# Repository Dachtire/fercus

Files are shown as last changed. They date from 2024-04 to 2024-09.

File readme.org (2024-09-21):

#+TITLE: Fercus
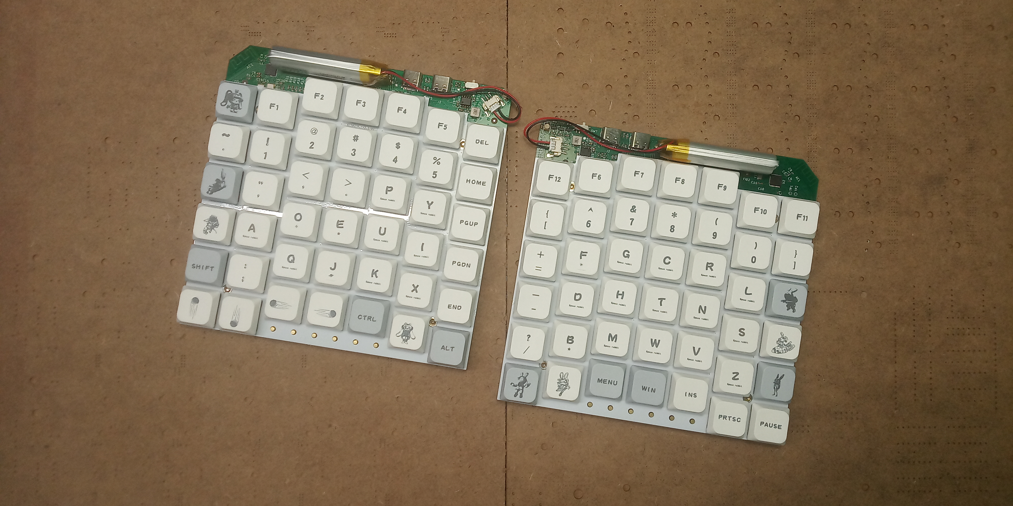
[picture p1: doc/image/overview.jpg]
Wireless Symmetry Optical Keyboard

* Firmware
** Connect via RF 2.4GHz Proprietary, BLE 5.3, USB
** COMMENT optical switch with diff trigger mode
# - schmitt trigger
# - adc trigger
# - adc difference
** COMMENT function
# - multiple layers
# - repeat mode

* Hardware
** Switch
6*7 keys of each side, low profile optical switch
# - raesha low profile optical switch
# - keychron low profile optical switch
# - razer low profile optical switch

** Spec
Dimension: 133 * 137 * 14.35 mm

Weight of each side: 159 ± 1 g

power input: DC 5V 500mA

# current: 40 mA * 7 * 15 / 1000 = 4.2 mA

** response time
|    |       tr |       tf | unit |
| pt |       18 |        5 | us   |
# | sw | 200-2000 | 200-2000 | us   |
The speed of optical switch depends on the speed of finger, the shortest time for finger to press a switch is about 200 us, but usually it takes a few milliseconds.
Test on mcu's adc at f_adc = 12MHz, f_s = 12 / 14 MHz, resolution = 12 bits. Get the average of the five.

** COMMENT test
|    | min | typ | max | unit | cond                    |
| pt | 0.2 |     | 0.3 | V    | ir 20mA, without switch |

* Manual
** fn key
fn1: switch layout

fn2: switch connection mode. long press: rf Unbind with dongle

fn3: battery status

fn4: power on led green. power off led red.

** usb connection
- usb1 to connect with pc
#+begin_src org
              ┌────┐              
              │ pc │              
              └▲──▲┘              
               │  │               
    ┌───usb────┘  └────usb───┐    
    │                        │    
┌───▼──┬──────┐    ┌──────┬──▼───┐
│ usb1 │ usb2 │    │ usb2 │ usb1 │
├──────┴──────┤    ├──────┴──────┤
│    left     │    │    right    │
└─────────────┘    └─────────────┘
#+end_src
- usb2 to connect between left and right
#+begin_src org
              ┌────┐                                 ┌────┐              
              │ pc │                                 │ pc │              
              └▲───┘                                 └───▲┘              
               │                                         │               
    ┌───usb────┘                                         └────usb───┐    
    │                                                               │    
    │      ┌───usb────┐                           ┌───usb────┐      │    
    │      │          │                           │          │      │    
┌───▼──┬───▼──┐    ┌──▼───┬──────┐     ┌──────┬───▼──┐    ┌──▼───┬──▼───┐
│ usb1 │ usb2 │    │ usb2 │ usb1 │     │ usb1 │ usb2 │    │ usb2 │ usb1 │
├──────┴──────┤    ├──────┴──────┤     ├──────┴──────┤    ├──────┴──────┤
│    left     │    │    right    │     │    left     │    │    right    │
└─────────────┘    └─────────────┘     └─────────────┘    └─────────────┘
#+end_src

#               ┌────┐              
#               │ pc │              
#               └▲──▲┘              
#                │  │               
#     ┌───usb────┘  └────usb───┐    
#     │                        │    
#     │      ┌───usb────┐      │    
#     │      │          │      │    
# ┌───▼──┬───▼──┐    ┌──▼───┬──▼───┐
# │ usb1 │ usb2 │    │ usb2 │ usb1 │
# ├──────┴──────┤    ├──────┴──────┤
# │    left     │    │    right    │
# └─────────────┘    └─────────────┘

** RF connection
#+begin_src org
              ┌────┐              
              │ pc │              
              └─▲──┘              
                │usb              
             ┌──▼───┐             
  ┌─wireless─►dongle◄─wireless─┐  
  │          └──────┘          │  
  │                            │  
┌─▼───────────┐    ┌───────────▼─┐
│     RF      │    │     RF      │
├─────────────┤    ├─────────────┤
│    left     │    │    right    │
└─────────────┘    └─────────────┘
#+end_src

** BLE connection
#+begin_src org
              ┌────┐              
  ┌─wireless──► pc ◄──wireless─┐  
  │           └────┘           │  
  │                            │  
┌─▼───────────┐    ┌───────────▼─┐
│    BLE      │    │    BLE      │
├─────────────┤    ├─────────────┤
│    left     │    │    right    │
└─────────────┘    └─────────────┘
#+end_src

** mix connection
#+begin_src org
              ┌────┐              
              │ pc │              
              └▲───┘              
               │                  
    ┌───usb────┘                  
    │                             
    │      ┌─wireless─┐           
    │      │          │           
┌───▼──┬───▼──┐    ┌──▼───┬──────┐
│ usb1 │  RF  │    │  RF  │ usb1 │
├──────┴──────┤    ├──────┴──────┤
│    left     │    │    right    │
└─────────────┘    └─────────────┘
#+end_src

** power
auto power on/off when usb cable connected/disconnected

when idle for a week, first use fn4 to power off in firmware, then turn off hardware power switch

** layout
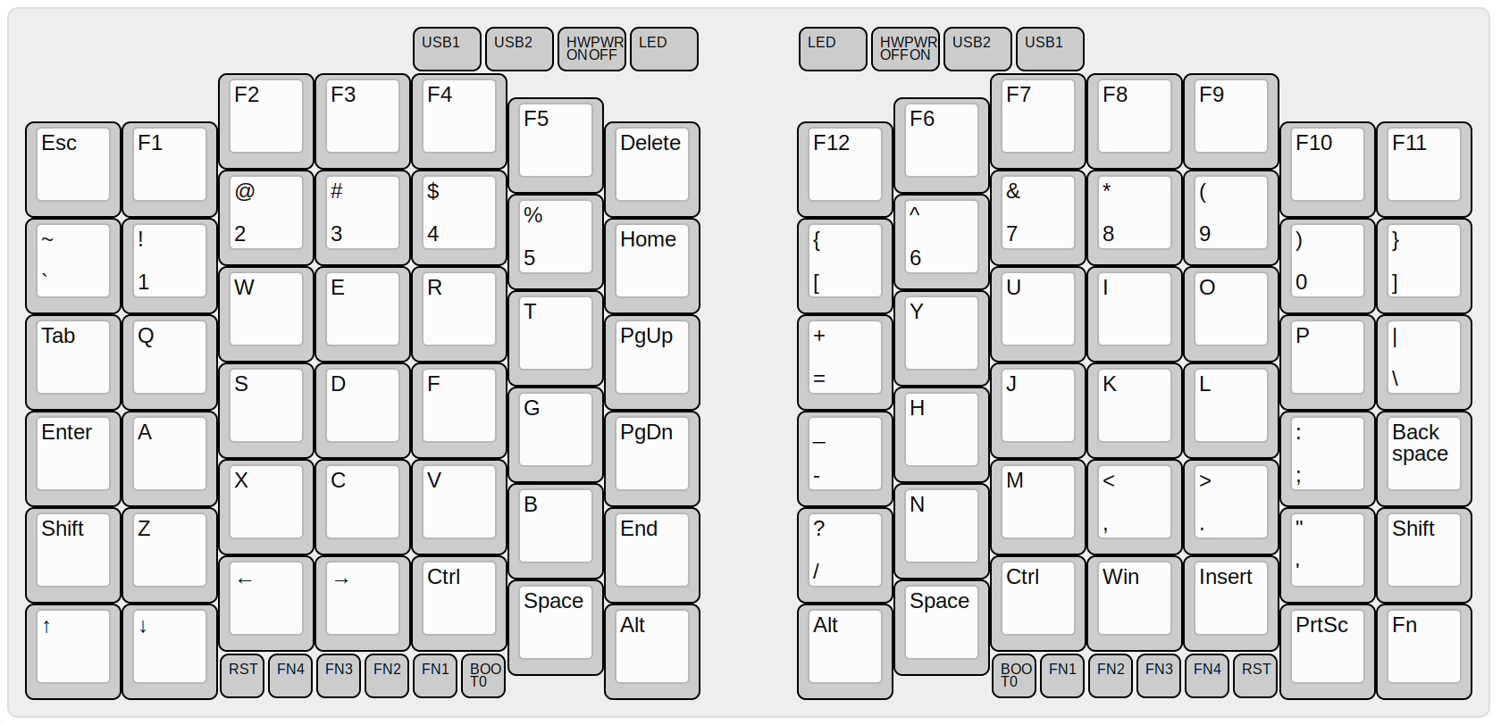
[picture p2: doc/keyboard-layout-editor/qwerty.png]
- qwerty

* Assembly
** compoment
- pcb 1.6mm thickness
- plate 1.2mm thickness
- nut m2 length 2.5mm, od 3mm
- screw m2 length 4mm
- rubber 1mm thickness
- li-on battery 101550 800mAh, molex picoblade 3 pin, 8 cm cable length
- usb-c to usb-c cable 1 m
- usb-c to usb-a cable 2 m
  
** COMMENT PCBA
soldering nut on pcb, or soldering nut on plate

** Overall
1. Install switches on the plate, the LED position of the switch is facing upwards.
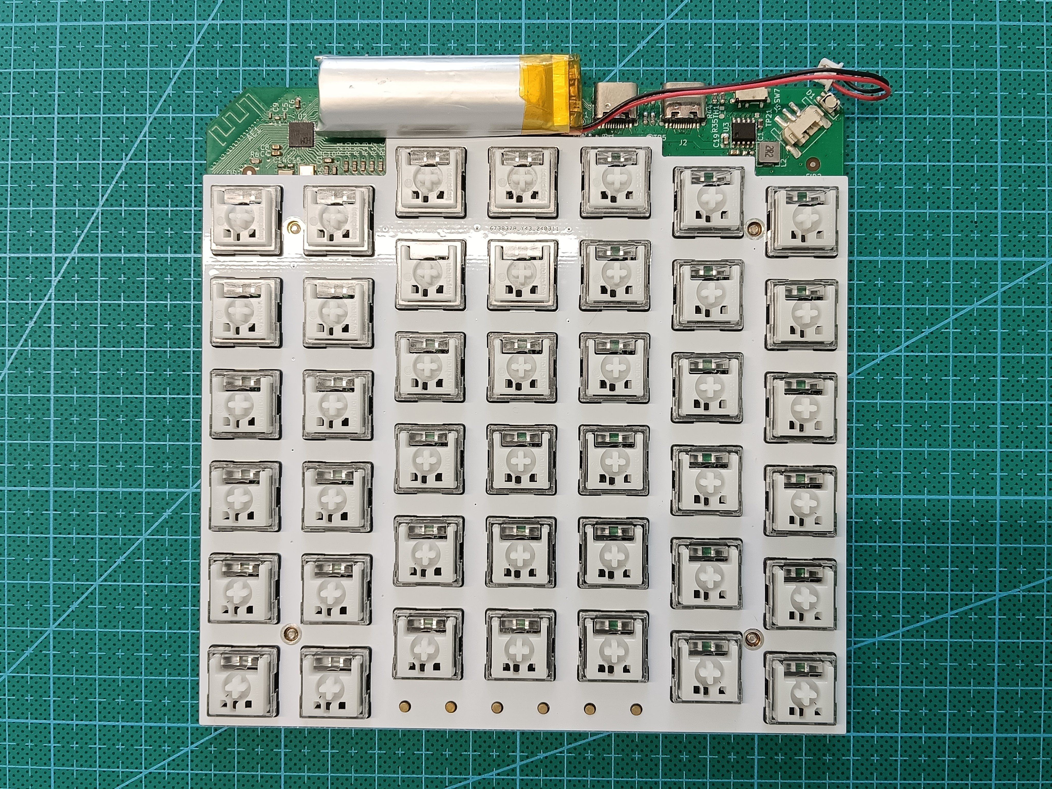
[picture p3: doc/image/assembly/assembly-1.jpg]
2. Install the plate to the PCB.
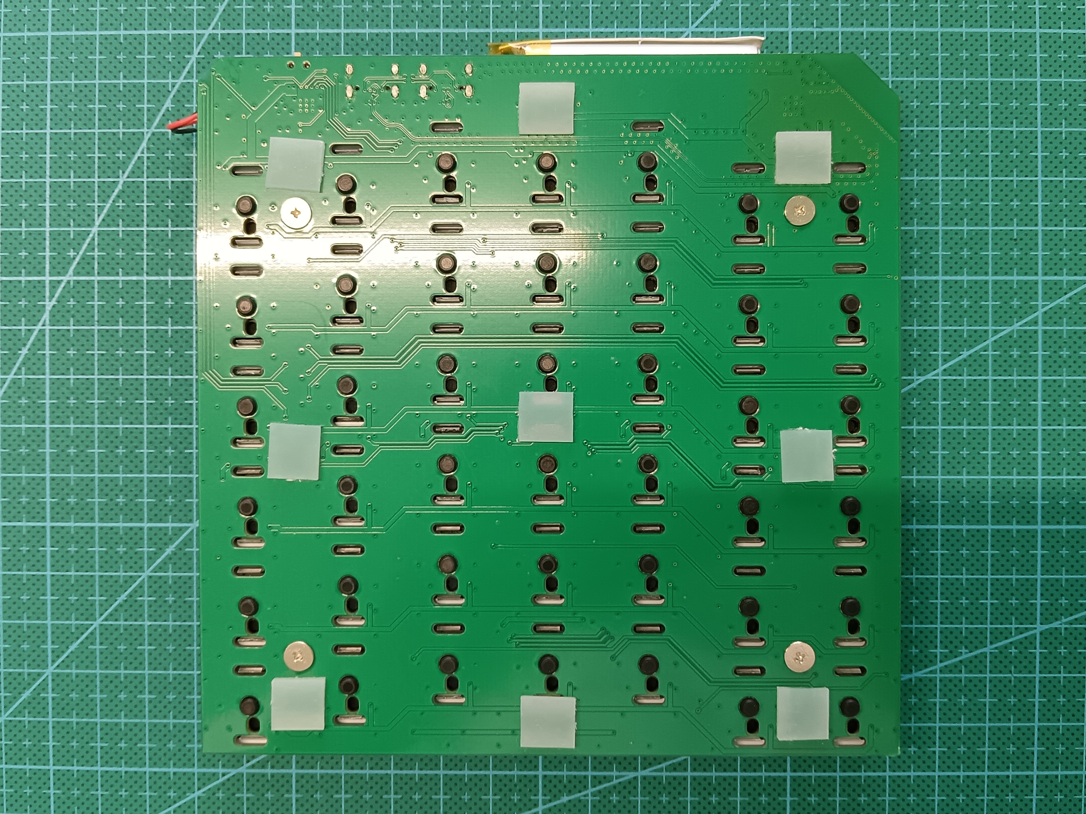
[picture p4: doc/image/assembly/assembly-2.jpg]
3. Install the screws.
4. Install keycaps.

* Thanks
[[https://discord.com/channels/715975244896272618][Optical Future Discord]]

* COMMENT FAQ
** COMMENT keys layout
*** thumb
finger splay increase the x axis distence between rows
more thumb keys may be hard to press
*** middle finger
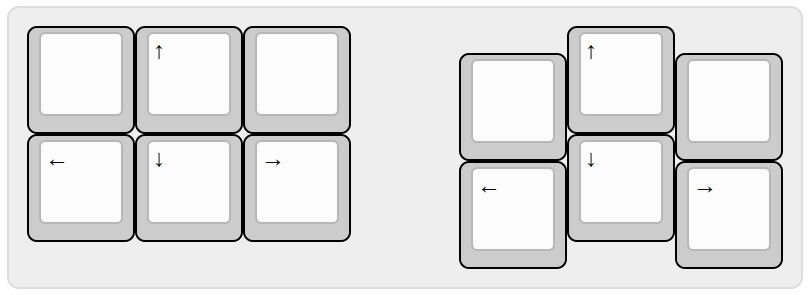
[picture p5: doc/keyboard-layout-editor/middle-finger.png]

mid finger at wsad postion, non stagger is better to press up
bad for playing fps game
# same for pinky stagger 8 mm instand of 12 mm

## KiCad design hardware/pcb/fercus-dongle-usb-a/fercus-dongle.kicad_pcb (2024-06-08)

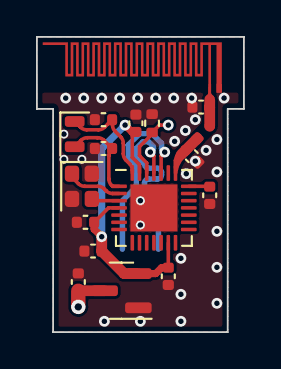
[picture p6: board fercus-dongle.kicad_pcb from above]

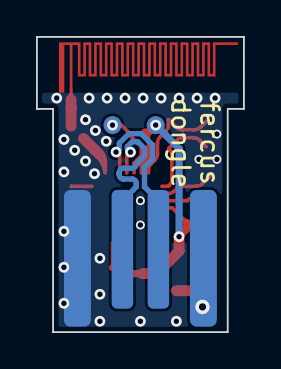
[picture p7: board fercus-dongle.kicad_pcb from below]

Board: 2 copper layers, 11.5 x 16.4 mm, 20 parts (3 on the bottom side), 13 nets.

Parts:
AE1: Antenna_Shield; ANT-F-1-2.4G-0.8MM-FR4-WCH_Left_Mask
C1, C2, C3: 100nF; C_0402_1005Metric
C4, C9, C10: 1uF; C_0402_1005Metric
C5, C6: 12pF; C_0402_1005Metric
C7, C8: 1.8pF; C_0402_1005Metric
J1: USB_A; USBAM-4P
L1: 1.8nH; L_0402_1005Metric
R1: 10kR; R_0402_1005Metric
TP1, TP2: TestPoint; TestPoint_Pad_D1.0mm
U1: CH32V208GBU6; QFN-28-1EP_4x4mm_P0.4mm_EP2.6x2.6mm
U2: XC6206P332MR; SOT-23
Y1: 32MHz; Crystal_SMD_2016-4Pin_2.0x1.6mm
Y2: 32.768kHz; Crystal_SMD_2012-2Pin_2.0x1.2mm

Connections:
+3.3V: C1.1, C2.1, C3.1, C10.1, TP1.1, U1.4 (VDDA), U1.13 (VDD_1), U1.27 (VDD_3), U2.2 (VO)
+5V: C9.1, J1.1 (VBUS), U2.3 (VI)
/VINTA: C4.1, U1.21 (VINTA)
ANT: C7.1, L1.1, U1.22 (ANT)
BOOT0: R1.1, TP2.1, U1.26 (PB8/BOOT0)
GND: AE1.2 (Shield), C1.2, C2.2, C3.2, C4.2, C5.2, C6.2, C7.2, C8.2, C9.2, C10.2, J1.4 (GND), R1.2, U1.29 (VSS), U2.1 (GND), Y1.2, Y1.4
unnamed: AE1.1 (A), C8.1, L1.2
OCS32IN: C5.1, U1.28 (PC14/OSC32_IN), Y2.1
OCS32OUT: C6.1, U1.1 (PC15/OSC32_OUT), Y2.2
OCSIN: U1.2 (OSC_IN), Y1.1
OCSOUT: U1.3 (OSC_OUT), Y1.3
usb2_N: J1.2 (D-), U1.24 (USB2_DM/PB6)
usb2_P: J1.3 (D+), U1.25 (USB2_DP/PB7)

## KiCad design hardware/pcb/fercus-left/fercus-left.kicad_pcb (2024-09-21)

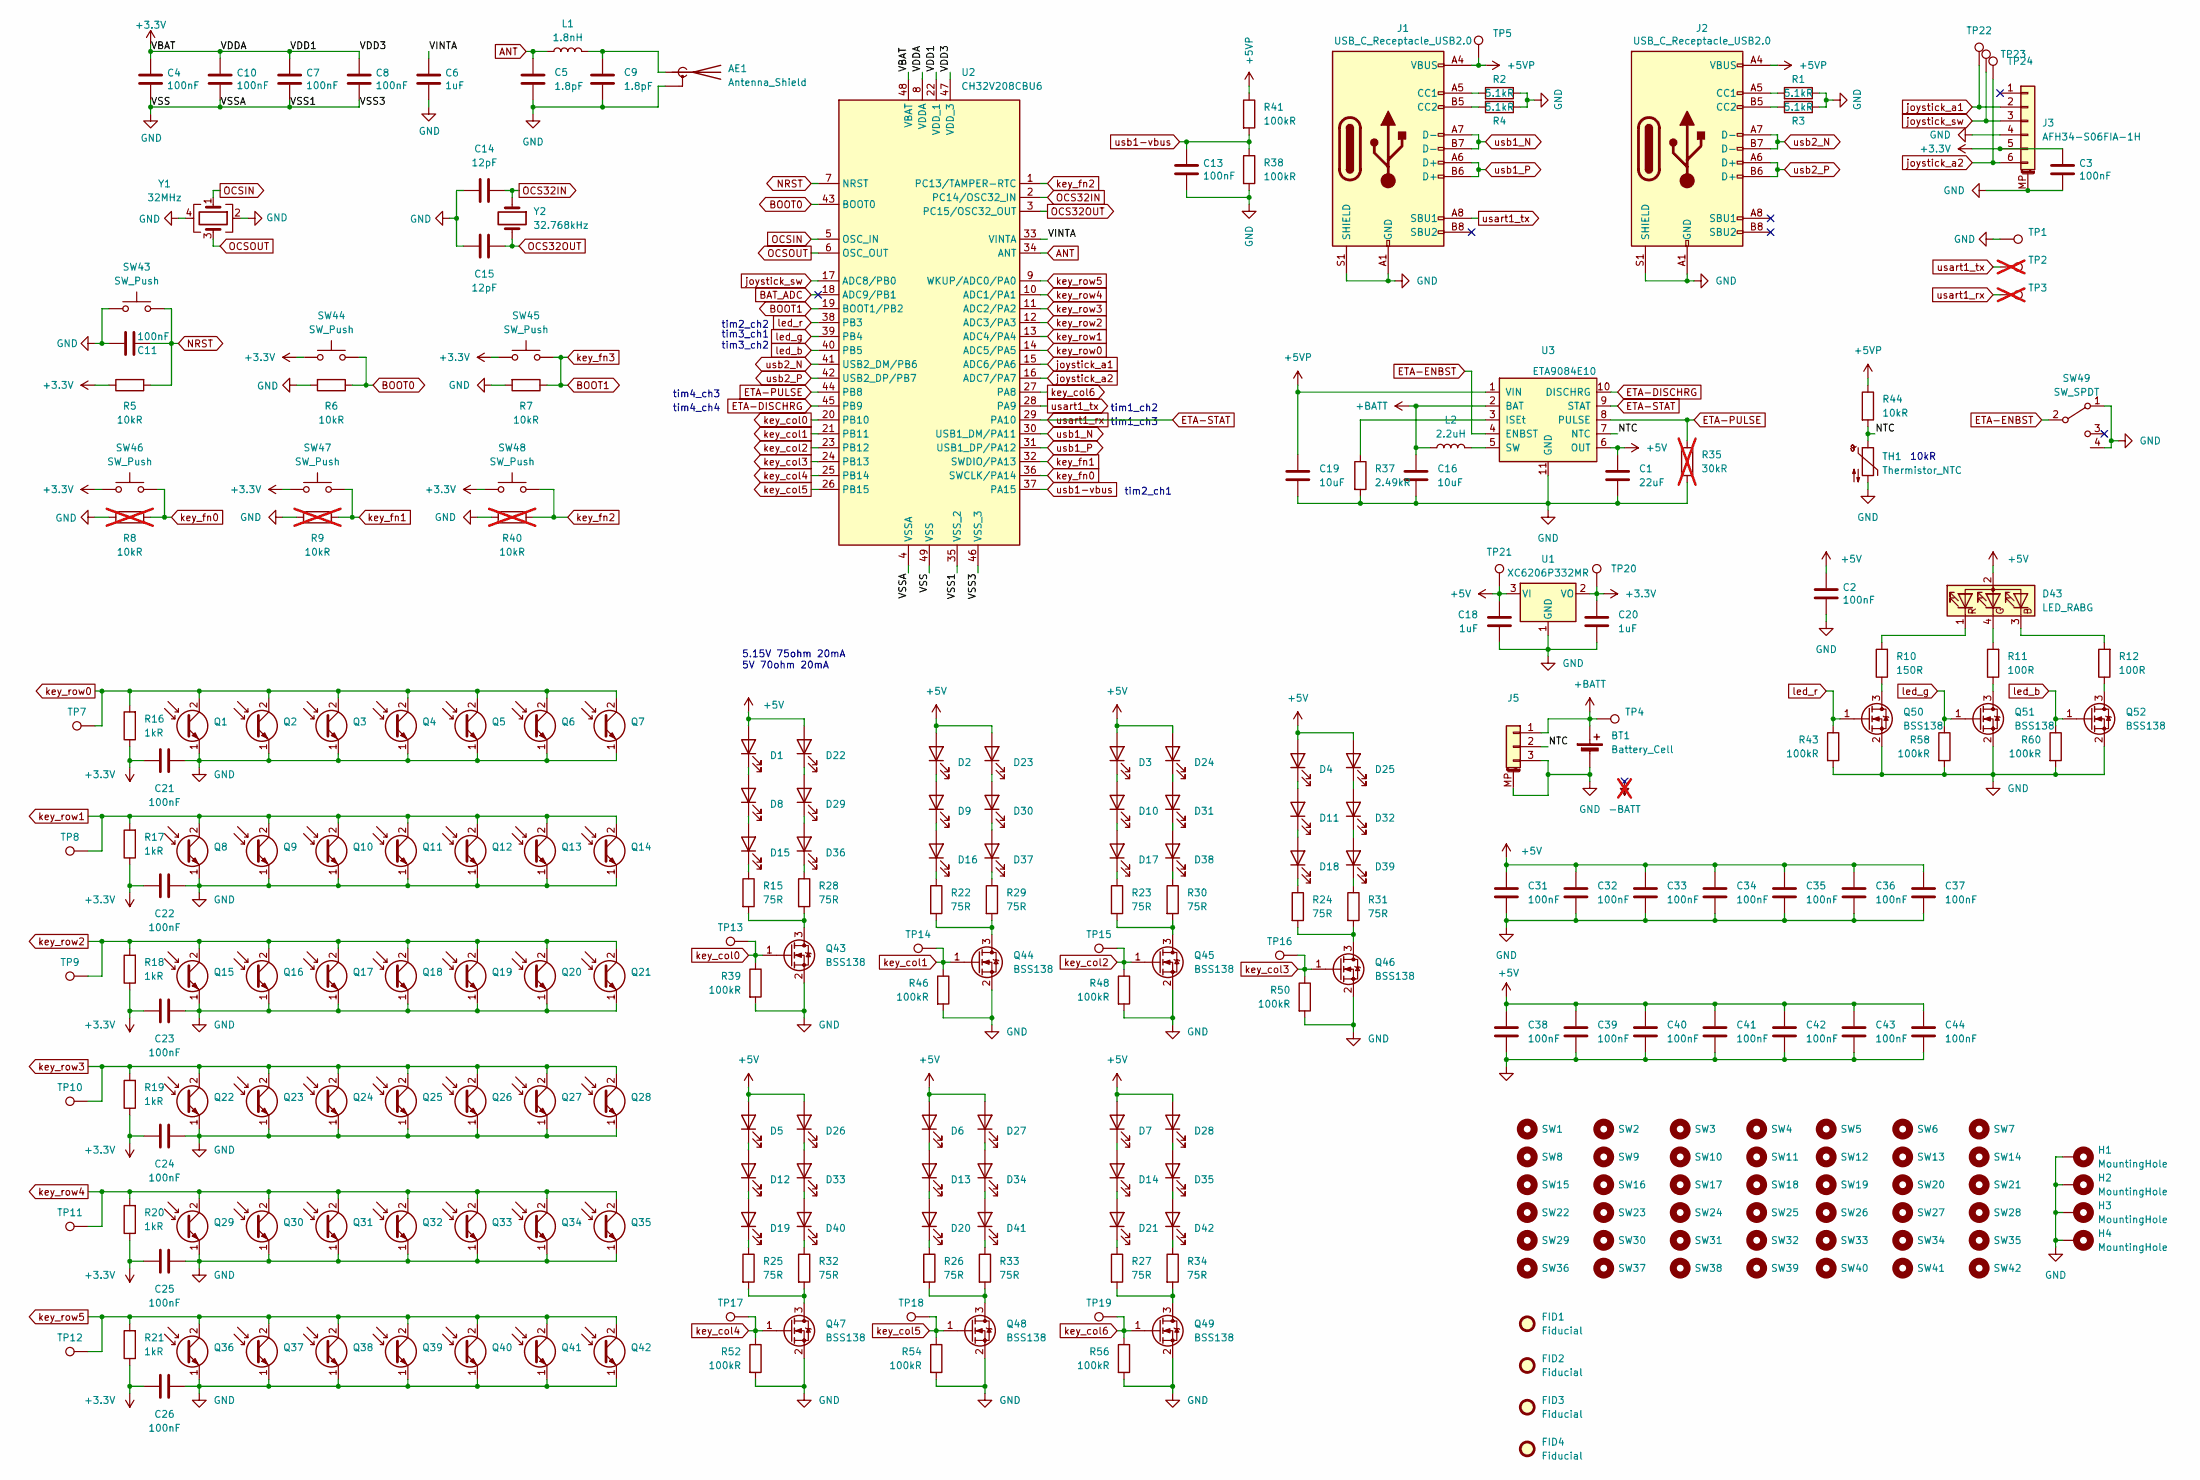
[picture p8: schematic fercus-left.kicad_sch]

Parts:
AE1: Antenna_Shield; WCH_MIFA-1_2.4G_1.6mm_FR4_Left_NoMask
BT1: Battery_Cell
C1: 22uF; C_0603_1608Metric
C2, C3, C4, C7, C8, C10, C11, C13, C21, C22, C23, C24, C25, C26, C31, C32, C33, C34, C35, C36, C37, C38, C39, C40, C41, C42, C43, C44: 100nF; C_0603_1608Metric
C5, C9: 1.8pF; C_0402_1005Metric
C6, C18, C20: 1uF; C_0603_1608Metric
C14, C15: 12pF; C_0402_1005Metric
C16: 10uF; C_0603_1608Metric
C19: 10uF; C_0805_2012Metric
D1, D2, D3, D4, D5, D6, D7, D8, D9, D10, D11, D12, D13, D14, D15, D16, D17, D18, D19, D20, D21, D22, D23, D24, D25, D26, D27, D28, D29, D30, D31, D32, D33, D34, D35, D36, D37, D38, D39, D40, D41, D42: KTR-0602IRC-850; KTR-0602IRC
D43: LED_RABG; Everlight_LED_RGB_PLCC-4
FID1, FID2, FID3, FID4: Fiducial; Fiducial_1mm_Mask3mm
H1, H2, H3, H4: MountingHole; MountingHole_2.2mm_M2_ISO14580_Pad
J1, J2: USB_C_Receptacle_USB2.0; USB_C_Receptacle_HRO_TYPE-C-31-M-12
J3: AFH34-S06FIA-1H; Jushuo_AFC42-S06FMA-1H_1x6-1MP_P0.50_Horizontal
J5: Molex_PicoBlade_53261-0371_1x03-1MP_P1.25mm_Horiz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; Molex_PicoBlade_53261-0371_1x03-1MP_P1.25mm_Horizontal
L1: 1.8nH; L_0402_1005Metric
L2: 2.2uH; L_Sunlord_MWSA0402S
Q1, Q2, Q3, Q4, Q5, Q6, Q7, Q8, Q9, Q10, Q11, Q12, Q13, Q14, Q15, Q16, Q17, Q18, Q19, Q20, Q21, Q22, Q23, Q24, Q25, Q26, Q27, Q28, Q29, Q30, Q31, Q32, Q33, Q34, Q35, Q36, Q37, Q38, Q39, Q40, Q41, Q42: KTR-0602PTD
Q43, Q44, Q45, Q46, Q47, Q48, Q49, Q50, Q51, Q52: BSS138; SOT-23
R1, R2, R3, R4: 5.1kR; R_0603_1608Metric
R5, R6, R7, R44: 10kR; R_0603_1608Metric
R8, R9, R40: 10kR; R_0603_1608Metric; not fitted
R10: 150R; R_0603_1608Metric
R11, R12: 100R; R_0603_1608Metric
R15, R22, R23, R24, R25, R26, R27, R28, R29, R30, R31, R32, R33, R34: 75R; R_0603_1608Metric
R16, R17, R18, R19, R20, R21: 1kR; R_0603_1608Metric
R35: 30kR; R_0603_1608Metric; not fitted
R37: 2.49kR; R_0402_1005Metric
R38, R39, R41, R43, R46, R48, R50, R52, R54, R56, R58, R60: 100kR; R_0603_1608Metric
SW1, SW2, SW3, SW4, SW5, SW6, SW7, SW8, SW9, SW10, SW11, SW12, SW13, SW14, SW15, SW16, SW17, SW18, SW19, SW20, SW21, SW22, SW23, SW24, SW25, SW26, SW27, SW28, SW29, SW30, SW31, SW32, SW33, SW34, SW35, SW36, SW37, SW38, SW39, SW40, SW41, SW42: SW_Optical; SW_RAESHA_Low_Profile_Optical
SW43, SW44, SW45, SW46, SW47, SW48: SW_Push; SW_SPST_TL3342
SW49: SW_SPDT; SW_SPDT_PCM12
TH1: Thermistor_NTC; R_0603_1608Metric
TP1, TP4, TP5, TP7, TP8, TP9, TP10, TP11, TP12, TP13, TP14, TP15, TP16, TP17, TP18, TP19, TP20, TP21, TP22, TP23, TP24: TestPoint; TestPoint_Pad_D1.0mm
TP2, TP3: TestPoint; TestPoint_Pad_D1.0mm; not fitted
U1: XC6206P332MR; SOT-23-3
U2: CH32V208CBU6; QFN-48-1EP_5x5mm_P0.35mm_EP3.7x3.7mm_ThermalVias_Drill0.3mm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
U3: ETA9084E10; SSOP-10-1EP_3.9x4.9mm_P1.00mm_EP2.4x2.8mm_ThermalVias_Drill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
Y1: 32MHz; Crystal_SMD_3225-4Pin_3.2x2.5mm
Y2: 32.768kHz; Crystal_SMD_3215-2Pin_3.2x1.5mm

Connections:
+3.3V: C3.1, C4.1, C7.1, C8.1, C10.1, C20.1, C21.1, C22.1, C23.1, C24.1, C25.1, C26.1, J3.5, R5.1, R16.1, R17.1, R18.1, R19.1, R20.1, R21.1, SW44.1, SW45.1, SW46.1, SW47.1, SW48.1, TP20.1, U1.2 (VO), U2.8 (VDDA), U2.22 (VDD_1), U2.47 (VDD_3), U2.48 (VBAT)
+5V: C1.1, C2.1, C18.1, C31.2, C32.2, C33.2, C34.2, C35.2, C36.2, C37.2, C38.2, C39.2, C40.2, C41.2, C42.2, C43.2, C44.2, D1.2 (A), D2.2 (A), D3.2 (A), D4.2 (A), D5.2 (A), D6.2 (A), D7.2 (A), D22.2 (A), D23.2 (A), D24.2 (A), D25.2 (A), D26.2 (A), D27.2 (A), D28.2 (A), D43.2 (A), TP21.1, U1.3 (VI), U3.6 (OUT)
+5VP: C19.1, J1.A4 (VBUS), J1.A9 (VBUS), J1.B4 (VBUS), J1.B9 (VBUS), J2.A4 (VBUS), J2.A9 (VBUS), J2.B4 (VBUS), J2.B9 (VBUS), R41.1, R44.1, TP5.1, U3.1 (VIN)
+BATT: BT1.1 (+), C16.1, J5.1, L2.1, TP4.1, U3.2 (BAT)
/NTC: J5.2, R44.2, TH1.1, U3.7 (NTC)
/VINTA: C6.1, U2.33 (VINTA)
ANT: C5.1, L1.1, U2.34 (ANT)
BAT_ADC: U2.18 (ADC9/PB1)
BOOT0: R6.1, SW44.2, U2.43 (BOOT0)
BOOT1: R7.1, SW45.2, U2.19 (BOOT1/PB2)
ETA-DISCHRG: U2.45 (PB9), U3.10 (DISCHRG)
ETA-ENBST: SW49.2 (B), U3.4 (ENBST)
ETA-PULSE: R35.1, U2.44 (PB8), U3.8 (PULSE)
ETA-STAT: TP3.1, U2.29 (PA10), U3.9 (STAT)
GND: AE1.2 (Shield), BT1.2 (-), C1.2, C2.2, C3.2, C4.2, C5.2, C6.2, C7.2, C8.2, C9.2, C10.2, C11.2, C13.2, C14.2, C15.2, C16.2, C18.2, C19.2, C20.2, C21.2, C22.2, C23.2, C24.2, C25.2, C26.2, C31.1, C32.1, C33.1, C34.1, C35.1, C36.1, C37.1, C38.1, C39.1, C40.1, C41.1, C42.1, C43.1, C44.1, H1.1, H2.1, H3.1, H4.1, J1.A1 (GND), J1.A12 (GND), J1.B1 (GND), J1.B12 (GND), J1.S1 (SHIELD), J2.A1 (GND), J2.A12 (GND), J2.B1 (GND), J2.B12 (GND), J2.S1 (SHIELD), J3.4, J3.MP (MountPin), J5.3, J5.MP (MountPin), Q1.1 (E), Q2.1 (E), Q3.1 (E), Q4.1 (E), Q5.1 (E), Q6.1 (E), Q7.1 (E), Q8.1 (E), Q9.1 (E), Q10.1 (E), Q11.1 (E), Q12.1 (E), Q13.1 (E), Q14.1 (E), Q15.1 (E), Q16.1 (E), Q17.1 (E), Q18.1 (E), Q19.1 (E), Q20.1 (E), Q21.1 (E), Q22.1 (E), Q23.1 (E), Q24.1 (E), Q25.1 (E), Q26.1 (E), Q27.1 (E), Q28.1 (E), Q29.1 (E), Q30.1 (E), Q31.1 (E), Q32.1 (E), Q33.1 (E), Q34.1 (E), Q35.1 (E), Q36.1 (E), Q37.1 (E), Q38.1 (E), Q39.1 (E), Q40.1 (E), Q41.1 (E), Q42.1 (E), Q43.2 (S), Q44.2 (S), Q45.2 (S), Q46.2 (S), Q47.2 (S), Q48.2 (S), Q49.2 (S), Q50.2 (S), Q51.2 (S), Q52.2 (S), R1.1, R2.1, R3.1, R4.1, R6.2, R7.2, R8.2, R9.2, R35.2, R37.2, R38.2, R39.2, R40.2, R43.2, R46.2, R48.2, R50.2, R52.2, R54.2, R56.2, R58.2, R60.2, SW43.1, SW49.1 (A), SW49.4, TH1.2, TP1.1, U1.1 (GND), U2.4 (VSSA), U2.35 (VSS_2), U2.46 (VSS_3), U2.49 (VSS), U3.11 (GND), Y1.2, Y1.4
NRST: C11.1, R5.2, SW43.2, U2.7 (NRST)
unnamed: AE1.1 (A), C9.1, L1.2
unnamed: D1.1 (K), D8.2 (A)
unnamed: D2.1 (K), D9.2 (A)
unnamed: D3.1 (K), D10.2 (A)
unnamed: D10.1 (K), D17.2 (A)
unnamed: D4.1 (K), D11.2 (A)
unnamed: D11.1 (K), D18.2 (A)
unnamed: D5.1 (K), D12.2 (A)
unnamed: D12.1 (K), D19.2 (A)
unnamed: D6.1 (K), D13.2 (A)
unnamed: D13.1 (K), D20.2 (A)
unnamed: D7.1 (K), D14.2 (A)
unnamed: D14.1 (K), D21.2 (A)
unnamed: D8.1 (K), D15.2 (A)
unnamed: D15.1 (K), R15.1
unnamed: D9.1 (K), D16.2 (A)
unnamed: D16.1 (K), R22.1
unnamed: D17.1 (K), R23.1
unnamed: D18.1 (K), R24.1
unnamed: D19.1 (K), R25.1
unnamed: D20.1 (K), R26.1
unnamed: D21.1 (K), R27.1
unnamed: D22.1 (K), D29.2 (A)
unnamed: D23.1 (K), D30.2 (A)
unnamed: D24.1 (K), D31.2 (A)
unnamed: D25.1 (K), D32.2 (A)
unnamed: D26.1 (K), D33.2 (A)
unnamed: D27.1 (K), D34.2 (A)
unnamed: D28.1 (K), D35.2 (A)
unnamed: D29.1 (K), D36.2 (A)
unnamed: D30.1 (K), D37.2 (A)
unnamed: D31.1 (K), D38.2 (A)
unnamed: D32.1 (K), D39.2 (A)
unnamed: D33.1 (K), D40.2 (A)
unnamed: D34.1 (K), D41.2 (A)
unnamed: D35.1 (K), D42.2 (A)
unnamed: D36.1 (K), R28.1
unnamed: D37.1 (K), R29.1
unnamed: D38.1 (K), R30.1
unnamed: D39.1 (K), R31.1
unnamed: D40.1 (K), R32.1
unnamed: D41.1 (K), R33.1
unnamed: D42.1 (K), R34.1
unnamed: D43.3 (BK), R12.2
unnamed: D43.4 (GK), R11.2
unnamed: D43.1 (RK), R10.2
unnamed: J1.A5 (CC1), R2.2
unnamed: J1.B5 (CC2), R4.2
unnamed: J2.A5 (CC1), R1.2
unnamed: J2.B5 (CC2), R3.2
unnamed: Q43.3 (D), R15.2, R28.2
unnamed: Q44.3 (D), R22.2, R29.2
unnamed: Q45.3 (D), R23.2, R30.2
unnamed: Q46.3 (D), R24.2, R31.2
unnamed: Q47.3 (D), R25.2, R32.2
unnamed: Q48.3 (D), R26.2, R33.2
unnamed: Q49.3 (D), R27.2, R34.2
unnamed: Q50.3 (D), R10.1
unnamed: Q51.3 (D), R11.1
unnamed: Q52.3 (D), R12.1
unnamed: R37.1, U3.3 (ISEt)
unnamed: L2.2, U3.5 (SW)
OCS32IN: C14.1, U2.2 (PC14/OSC32_IN), Y2.1
OCS32OUT: C15.1, U2.3 (PC15/OSC32_OUT), Y2.2
OCSIN: U2.5 (OSC_IN), Y1.1
OCSOUT: U2.6 (OSC_OUT), Y1.3
joystick_a1: J3.2, TP22.1, U2.15 (ADC6/PA6)
joystick_a2: J3.6, TP24.1, U2.16 (ADC7/PA7)
joystick_sw: J3.3, TP23.1, U2.17 (ADC8/PB0)
key_col0: Q43.1 (G), R39.1, TP13.1, U2.20 (PB10)
key_col1: Q44.1 (G), R46.1, TP14.1, U2.21 (PB11)
key_col2: Q45.1 (G), R48.1, TP15.1, U2.23 (PB12)
key_col3: Q46.1 (G), R50.1, TP16.1, U2.24 (PB13)
key_col4: Q47.1 (G), R52.1, TP17.1, U2.25 (PB14)
key_col5: Q48.1 (G), R54.1, TP18.1, U2.26 (PB15)
key_col6: Q49.1 (G), R56.1, TP19.1, U2.27 (PA8)
key_fn0: R8.1, SW46.2, U2.36 (SWCLK/PA14)
key_fn1: R9.1, SW47.2, U2.32 (SWDIO/PA13)
key_fn2: R40.1, SW48.2, U2.1 (PC13/TAMPER-RTC)
key_row0: Q1.2 (C), Q2.2 (C), Q3.2 (C), Q4.2 (C), Q5.2 (C), Q6.2 (C), Q7.2 (C), R16.2, TP7.1, U2.14 (ADC5/PA5)
key_row1: Q8.2 (C), Q9.2 (C), Q10.2 (C), Q11.2 (C), Q12.2 (C), Q13.2 (C), Q14.2 (C), R17.2, TP8.1, U2.13 (ADC4/PA4)
key_row2: Q15.2 (C), Q16.2 (C), Q17.2 (C), Q18.2 (C), Q19.2 (C), Q20.2 (C), Q21.2 (C), R18.2, TP9.1, U2.12 (ADC3/PA3)
key_row3: Q22.2 (C), Q23.2 (C), Q24.2 (C), Q25.2 (C), Q26.2 (C), Q27.2 (C), Q28.2 (C), R19.2, TP10.1, U2.11 (ADC2/PA2)
key_row4: Q29.2 (C), Q30.2 (C), Q31.2 (C), Q32.2 (C), Q33.2 (C), Q34.2 (C), Q35.2 (C), R20.2, TP11.1, U2.10 (ADC1/PA1)
key_row5: Q36.2 (C), Q37.2 (C), Q38.2 (C), Q39.2 (C), Q40.2 (C), Q41.2 (C), Q42.2 (C), R21.2, TP12.1, U2.9 (WKUP/ADC0/PA0)
led_b: Q52.1 (G), R60.1, U2.40 (PB5)
led_g: Q51.1 (G), R58.1, U2.39 (PB4)
led_r: Q50.1 (G), R43.1, U2.38 (PB3)
usart1_tx: J1.A8 (SBU1), TP2.1, U2.28 (PA9)
usb1-vbus: C13.1, R38.1, R41.2, U2.37 (PA15)
usb1_N: J1.A7 (D-), J1.B7 (D-), U2.30 (USB1_DM/PA11)
usb1_P: J1.A6 (D+), J1.B6 (D+), U2.31 (USB1_DP/PA12)
usb2_N: J2.A7 (D-), J2.B7 (D-), U2.41 (USB2_DM/PB6)
usb2_P: J2.A6 (D+), J2.B6 (D+), U2.42 (USB2_DP/PB7)

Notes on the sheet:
tim4_ch4
tim1_ch3
tim2_ch2
10kR
5.15V 75ohm 20mA 5V 70ohm 20mA
tim2_ch1
tim4_ch3
tim1_ch2
tim3_ch2
tim3_ch1

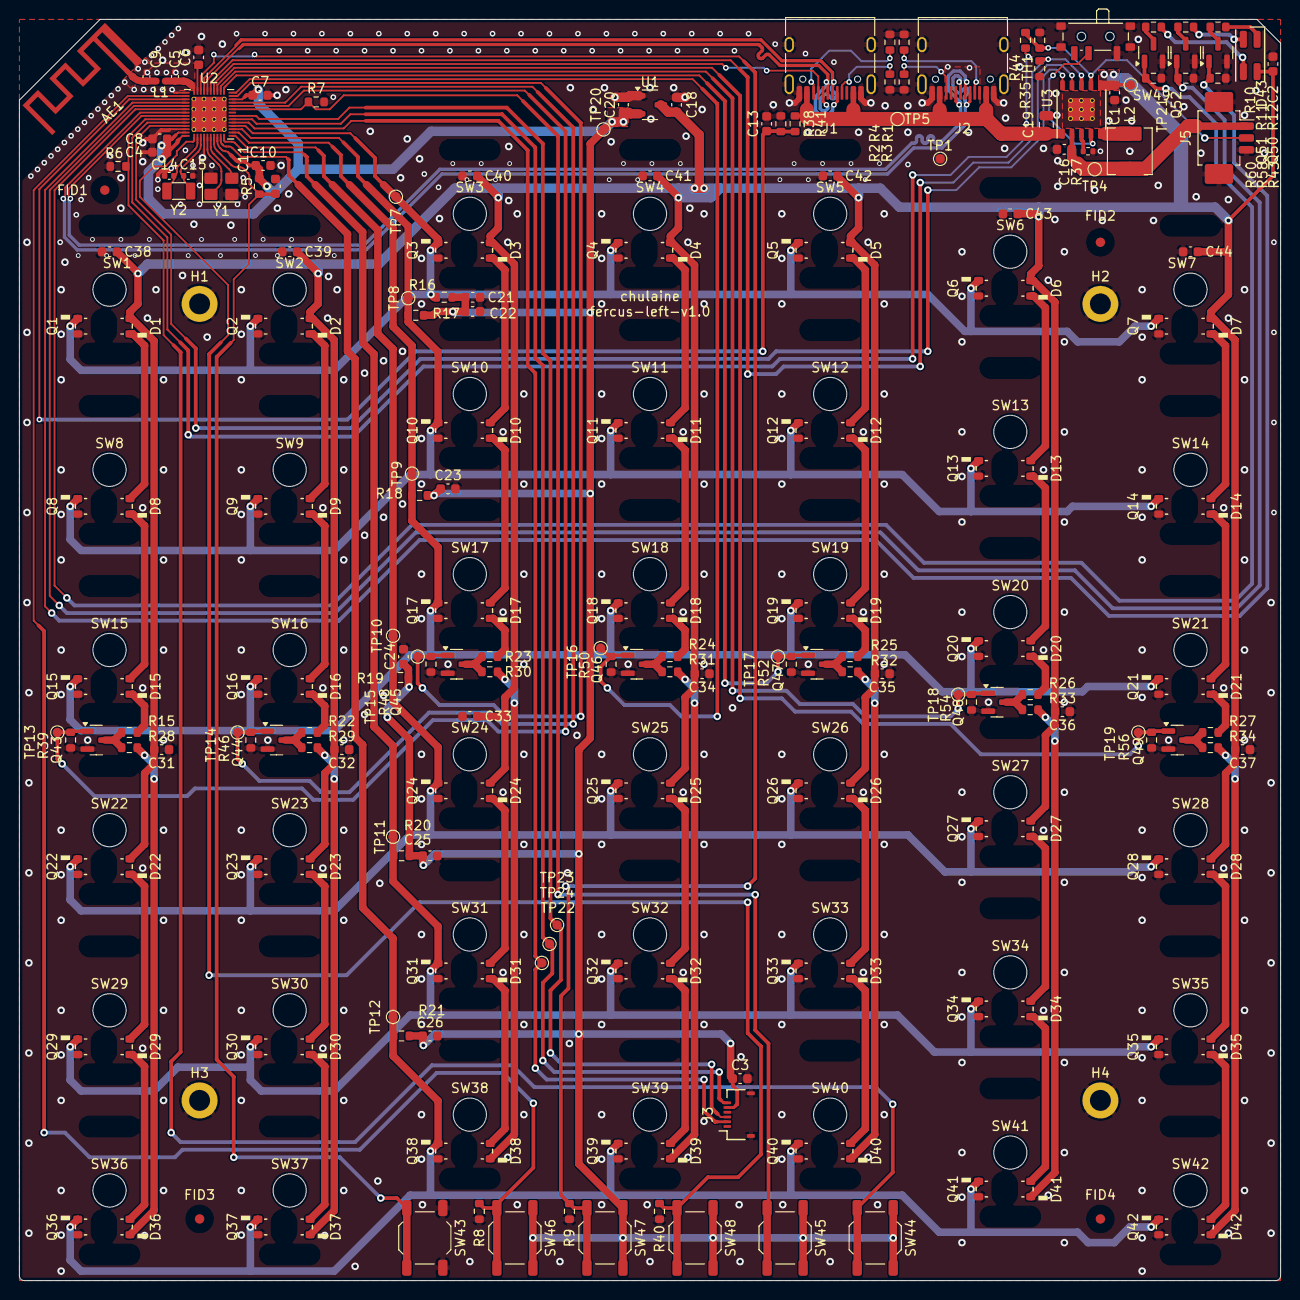
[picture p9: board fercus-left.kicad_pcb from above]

Board: 2 copper layers, 133.0 x 133.0 mm, 272 parts (0 on the bottom side), 109 nets.

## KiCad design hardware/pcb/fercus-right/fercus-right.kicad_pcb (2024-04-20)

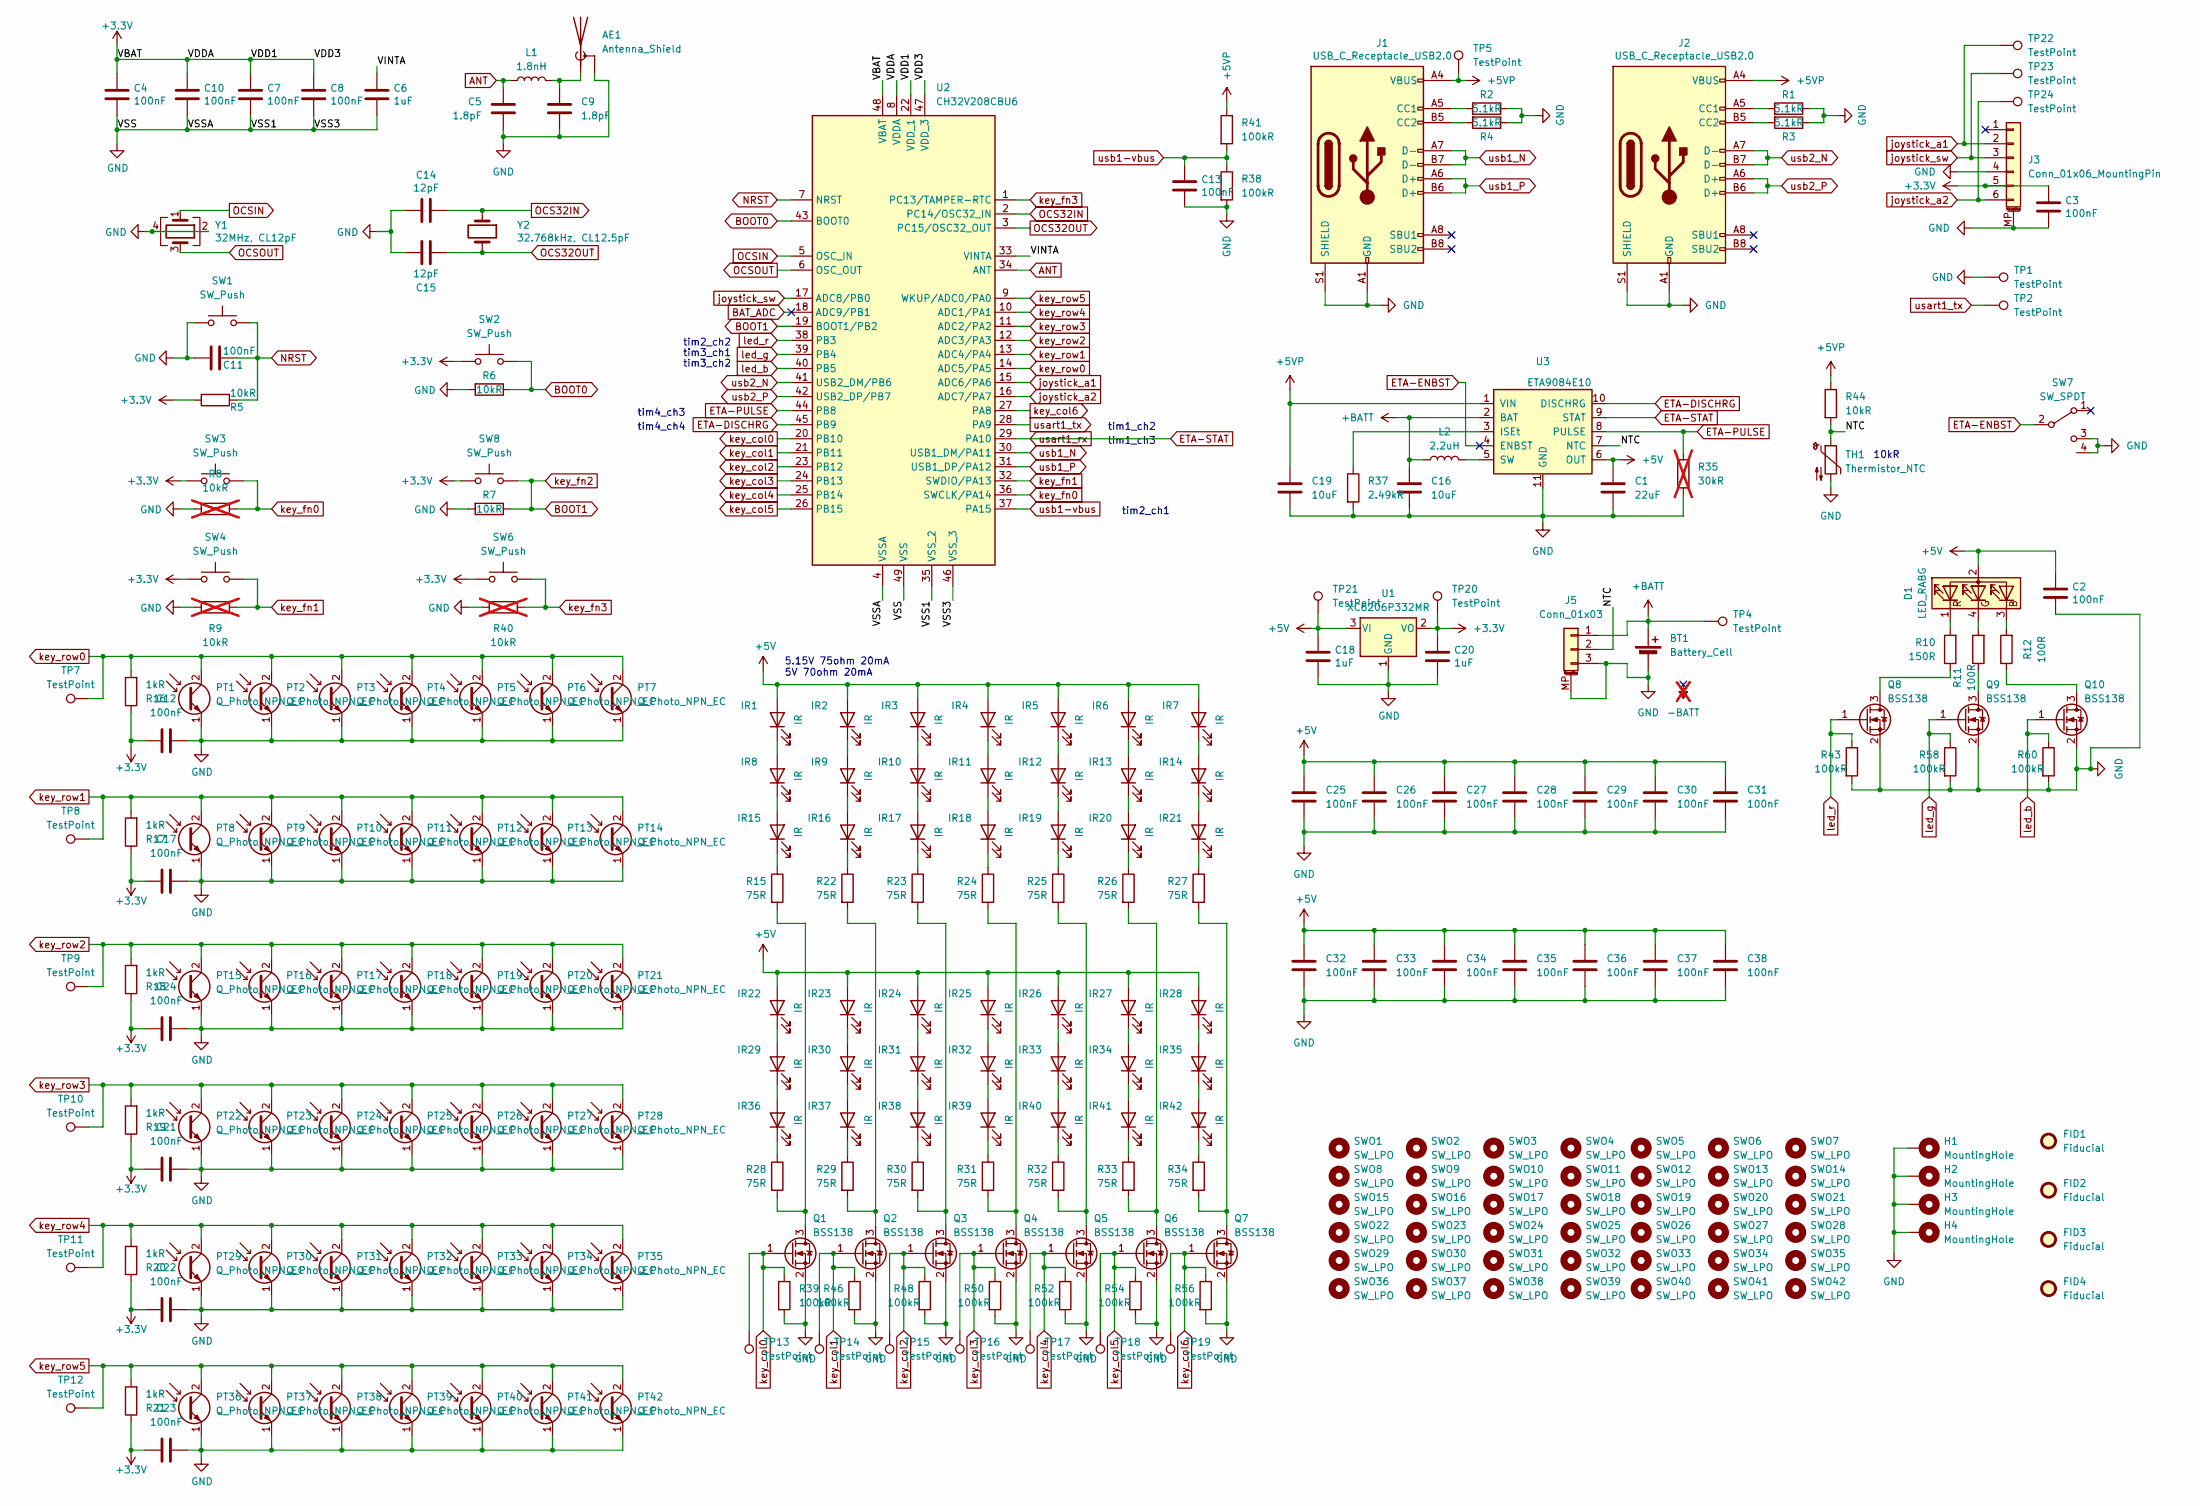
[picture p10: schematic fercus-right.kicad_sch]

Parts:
AE1: Antenna_Shield; ANT-F-1-2.4G-1.2MM-FR4-WCH_Right_NoMask
BT1: Battery_Cell
C1: 22uF; C_0603_1608Metric
C2, C3, C12, C13, C17, C21, C22, C23, C24, C25, C26, C27, C28, C29, C30, C31, C32, C33, C34, C35, C36, C37, C38: 100nF; C_0603_1608Metric
C4, C7, C8, C10, C11: 100nF; C_0402_1005Metric
C5, C9: 1.8pF; C_0402_1005Metric
C6: 1uF; C_0402_1005Metric
C14, C15: 12pF; C_0402_1005Metric
C16: 10uF; C_0603_1608Metric
C18, C20: 1uF; C_0603_1608Metric
C19: 10uF; C_0805_2012Metric
D1: LED_RABG; Everlight_LED_RGB_PLCC-4
FID1, FID2, FID3, FID4: Fiducial; Fiducial_1mm_Mask3mm
H1, H2, H3, H4: MountingHole; MountingHole_2.2mm_M2_ISO14580_Pad
IR1, IR2, IR3, IR4, IR5, IR6, IR7, IR8, IR9, IR10, IR11, IR12, IR13, IR14, IR15, IR16, IR17, IR18, IR19, IR20, IR21, IR22, IR23, IR24, IR25, IR26, IR27, IR28, IR29, IR30, IR31, IR32, IR33, IR34, IR35, IR36, IR37, IR38, IR39, IR40, IR41, IR42: IR; KTR-0602IRC
J1, J2: USB_C_Receptacle_USB2.0; USB_C_Receptacle_HRO_TYPE-C-31-M-12
J3: Conn_01x06_MountingPin; Jushuo_AFC42-S06FMA-1H_1x6-1MP_P0.50_Horizontal
J5: Conn_01x03; Molex_PicoBlade_53261-0371_1x03-1MP_P1.25mm_Horizontal
L1: 1.8nH; L_0402_1005Metric
L2: 2.2uH; L_Sunlord_MWSA0402S
PT1, PT2, PT3, PT4, PT5, PT6, PT7, PT8, PT9, PT10, PT11, PT12, PT13, PT14, PT15, PT16, PT17, PT18, PT19, PT20, PT21, PT22, PT23, PT24, PT25, PT26, PT27, PT28, PT29, PT30, PT31, PT32, PT33, PT34, PT35, PT36, PT37, PT38, PT39, PT40, PT41, PT42: Q_Photo_NPN_EC; KTR-0602PTD
Q1, Q2, Q3, Q4, Q5, Q6, Q7, Q8, Q9, Q10: BSS138; SOT-23
R1, R2, R3, R4: 5.1kR; R_0603_1608Metric
R5, R6, R7, R44: 10kR; R_0603_1608Metric
R8, R9, R40: 10kR; R_0603_1608Metric; not fitted
R10: 150R; R_0603_1608Metric
R11, R12: 100R; R_0603_1608Metric
R15, R22, R23, R24, R25, R26, R27, R28, R29, R30, R31, R32, R33, R34: 75R; R_0603_1608Metric
R16, R17, R18, R19, R20, R21: 1kR; R_0603_1608Metric
R35: 30kR; R_0603_1608Metric; not fitted
R37: 2.49kR; R_0603_1608Metric
R38, R39, R41, R43, R46, R48, R50, R52, R54, R56, R58, R60: 100kR; R_0603_1608Metric
SW1, SW2, SW3, SW4, SW6, SW8: SW_Push; SW_SPST_TL3342
SW7: SW_SPDT; SW_SPDT_PCM12
SWO1, SWO2, SWO3, SWO4, SWO5, SWO6, SWO7, SWO8, SWO9, SWO10, SWO11, SWO12, SWO13, SWO14, SWO15, SWO16, SWO17, SWO18, SWO19, SWO20, SWO21, SWO22, SWO23, SWO24, SWO25, SWO26, SWO27, SWO28, SWO29, SWO30, SWO31, SWO32, SWO33, SWO34, SWO35, SWO36, SWO37, SWO38, SWO39, SWO40, SWO41, SWO42: SW_LPO; SW_RAESHA_Low_Profile_Optical
TH1: Thermistor_NTC; R_0603_1608Metric
TP1, TP2, TP4, TP5, TP7, TP8, TP9, TP10, TP11, TP12, TP13, TP14, TP15, TP16, TP17, TP18, TP19, TP20, TP21, TP22, TP23, TP24: TestPoint; TestPoint_Pad_D1.0mm
U1: XC6206P332MR; SOT-23-3
U2: CH32V208CBU6; QFN-48-1EP_5x5mm_P0.35mm_EP3.7x3.7mm_ThermalVias_Drill0.3mm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
U3: ETA9084E10; SSOP-10-1EP_3.9x4.9mm_P1.00mm_EP2.4x2.8mm_ThermalVias_Drill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
Y1: 32MHz, CL12pF; Crystal_SMD_2016-4Pin_2.0x1.6mm
Y2: 32.768kHz, CL12.5pF; Crystal_SMD_2012-2Pin_2.0x1.2mm

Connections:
+3.3V: C3.1, C4.1, C7.1, C8.1, C10.1, C12.1, C17.1, C20.1, C21.1, C22.1, C23.1, C24.1, J3.5, R5.1, R16.1, R17.1, R18.1, R19.1, R20.1, R21.1, SW2.1, SW3.1, SW4.1, SW6.1, SW8.1, TP20.1, U1.2 (VO), U2.8 (VDDA), U2.22 (VDD_1), U2.47 (VDD_3), U2.48 (VBAT)
+5V: C1.1, C2.1, C18.1, C25.2, C26.2, C27.2, C28.2, C29.2, C30.2, C31.2, C32.2, C33.2, C34.2, C35.2, C36.2, C37.2, C38.2, D1.2 (A), IR1.2 (A), IR2.2 (A), IR3.2 (A), IR4.2 (A), IR5.2 (A), IR6.2 (A), IR7.2 (A), IR22.2 (A), IR23.2 (A), IR24.2 (A), IR25.2 (A), IR26.2 (A), IR27.2 (A), IR28.2 (A), TP21.1, U1.3 (VI), U3.6 (OUT)
+5VP: C19.1, J1.A4 (VBUS), J1.A9 (VBUS), J1.B4 (VBUS), J1.B9 (VBUS), J2.A4 (VBUS), J2.A9 (VBUS), J2.B4 (VBUS), J2.B9 (VBUS), R41.1, R44.1, TP5.1, U3.1 (VIN)
+BATT: BT1.1 (+), C16.1, J5.1, L2.1, TP4.1, U3.2 (BAT)
/NTC: J5.2, R44.2, TH1.1, U3.7 (NTC)
/VINTA: C6.1, U2.33 (VINTA)
ANT: C5.1, L1.1, U2.34 (ANT)
BAT_ADC: U2.18 (ADC9/PB1)
BOOT0: R6.1, SW2.2, U2.43 (BOOT0)
BOOT1: R7.1, SW8.2, U2.19 (BOOT1/PB2)
ETA-DISCHRG: U2.45 (PB9), U3.10 (DISCHRG)
ETA-ENBST: SW7.2 (B), U3.4 (ENBST)
ETA-PULSE: R35.1, U2.44 (PB8), U3.8 (PULSE)
ETA-STAT: U2.29 (PA10), U3.9 (STAT)
GND: AE1.2 (Shield), BT1.2 (-), C1.2, C2.2, C3.2, C4.2, C5.2, C6.2, C7.2, C8.2, C9.2, C10.2, C11.2, C12.2, C13.2, C14.2, C15.2, C16.2, C17.2, C18.2, C19.2, C20.2, C21.2, C22.2, C23.2, C24.2, C25.1, C26.1, C27.1, C28.1, C29.1, C30.1, C31.1, C32.1, C33.1, C34.1, C35.1, C36.1, C37.1, C38.1, H1.1, H2.1, H3.1, H4.1, J1.A1 (GND), J1.A12 (GND), J1.B1 (GND), J1.B12 (GND), J1.S1 (SHIELD), J2.A1 (GND), J2.A12 (GND), J2.B1 (GND), J2.B12 (GND), J2.S1 (SHIELD), J3.4, J3.MP (MountPin), J5.3, J5.MP (MountPin), PT1.1 (E), PT2.1 (E), PT3.1 (E), PT4.1 (E), PT5.1 (E), PT6.1 (E), PT7.1 (E), PT8.1 (E), PT9.1 (E), PT10.1 (E), PT11.1 (E), PT12.1 (E), PT13.1 (E), PT14.1 (E), PT15.1 (E), PT16.1 (E), PT17.1 (E), PT18.1 (E), PT19.1 (E), PT20.1 (E), PT21.1 (E), PT22.1 (E), PT23.1 (E), PT24.1 (E), PT25.1 (E), PT26.1 (E), PT27.1 (E), PT28.1 (E), PT29.1 (E), PT30.1 (E), PT31.1 (E), PT32.1 (E), PT33.1 (E), PT34.1 (E), PT35.1 (E), PT36.1 (E), PT37.1 (E), PT38.1 (E), PT39.1 (E), PT40.1 (E), PT41.1 (E), PT42.1 (E), Q1.2 (S), Q2.2 (S), Q3.2 (S), Q4.2 (S), Q5.2 (S), Q6.2 (S), Q7.2 (S), Q8.2 (S), Q9.2 (S), Q10.2 (S), R1.1, R2.1, R3.1, R4.1, R6.2, R7.2, R8.2, R9.2, R35.2, R37.2, R38.2, R39.2, R40.2, R43.2, R46.2, R48.2, R50.2, R52.2, R54.2, R56.2, R58.2, R60.2, SW1.1, SW7.3 (C), SW7.4, TH1.2, TP1.1, U1.1 (GND), U2.4 (VSSA), U2.35 (VSS_2), U2.46 (VSS_3), U2.49 (VSS), U3.11 (GND), Y1.2, Y1.4
NRST: C11.1, R5.2, SW1.2, U2.7 (NRST)
unnamed: AE1.1 (A), C9.1, L1.2
unnamed: D1.3 (BK), R12.2
unnamed: D1.4 (GK), R11.2
unnamed: D1.1 (RK), R10.2
unnamed: IR1.1 (K), IR8.2 (A)
unnamed: IR2.1 (K), IR9.2 (A)
unnamed: IR3.1 (K), IR10.2 (A)
unnamed: IR10.1 (K), IR17.2 (A)
unnamed: IR4.1 (K), IR11.2 (A)
unnamed: IR11.1 (K), IR18.2 (A)
unnamed: IR5.1 (K), IR12.2 (A)
unnamed: IR12.1 (K), IR19.2 (A)
unnamed: IR6.1 (K), IR13.2 (A)
unnamed: IR13.1 (K), IR20.2 (A)
unnamed: IR7.1 (K), IR14.2 (A)
unnamed: IR14.1 (K), IR21.2 (A)
unnamed: IR8.1 (K), IR15.2 (A)
unnamed: IR15.1 (K), R15.1
unnamed: IR9.1 (K), IR16.2 (A)
unnamed: IR16.1 (K), R22.1
unnamed: IR17.1 (K), R23.1
unnamed: IR18.1 (K), R24.1
unnamed: IR19.1 (K), R25.1
unnamed: IR20.1 (K), R26.1
unnamed: IR21.1 (K), R27.1
unnamed: IR22.1 (K), IR29.2 (A)
unnamed: IR23.1 (K), IR30.2 (A)
unnamed: IR24.1 (K), IR31.2 (A)
unnamed: IR25.1 (K), IR32.2 (A)
unnamed: IR26.1 (K), IR33.2 (A)
unnamed: IR27.1 (K), IR34.2 (A)
unnamed: IR28.1 (K), IR35.2 (A)
unnamed: IR29.1 (K), IR36.2 (A)
unnamed: IR30.1 (K), IR37.2 (A)
unnamed: IR31.1 (K), IR38.2 (A)
unnamed: IR32.1 (K), IR39.2 (A)
unnamed: IR33.1 (K), IR40.2 (A)
unnamed: IR34.1 (K), IR41.2 (A)
unnamed: IR35.1 (K), IR42.2 (A)
unnamed: IR36.1 (K), R28.1
unnamed: IR37.1 (K), R29.1
unnamed: IR38.1 (K), R30.1
unnamed: IR39.1 (K), R31.1
unnamed: IR40.1 (K), R32.1
unnamed: IR41.1 (K), R33.1
unnamed: IR42.1 (K), R34.1
unnamed: J1.A5 (CC1), R2.2
unnamed: J1.B5 (CC2), R4.2
unnamed: J2.A5 (CC1), R1.2
unnamed: J2.B5 (CC2), R3.2
unnamed: Q1.3 (D), R15.2, R28.2
unnamed: Q2.3 (D), R22.2, R29.2
unnamed: Q3.3 (D), R23.2, R30.2
unnamed: Q4.3 (D), R24.2, R31.2
unnamed: Q5.3 (D), R25.2, R32.2
unnamed: Q6.3 (D), R26.2, R33.2
unnamed: Q7.3 (D), R27.2, R34.2
unnamed: Q8.3 (D), R10.1
unnamed: Q9.3 (D), R11.1
unnamed: Q10.3 (D), R12.1
unnamed: R37.1, U3.3 (ISEt)
unnamed: L2.2, U3.5 (SW)
OCS32IN: C14.1, U2.2 (PC14/OSC32_IN), Y2.1
OCS32OUT: C15.1, U2.3 (PC15/OSC32_OUT), Y2.2
OCSIN: U2.5 (OSC_IN), Y1.1
OCSOUT: U2.6 (OSC_OUT), Y1.3
joystick_a1: J3.2, TP22.1, U2.15 (ADC6/PA6)
joystick_a2: J3.6, TP24.1, U2.16 (ADC7/PA7)
joystick_sw: J3.3, TP23.1, U2.17 (ADC8/PB0)
key_col0: Q1.1 (G), R39.1, TP13.1, U2.20 (PB10)
key_col1: Q2.1 (G), R46.1, TP14.1, U2.21 (PB11)
key_col2: Q3.1 (G), R48.1, TP15.1, U2.23 (PB12)
key_col3: Q4.1 (G), R50.1, TP16.1, U2.24 (PB13)
key_col4: Q5.1 (G), R52.1, TP17.1, U2.25 (PB14)
key_col5: Q6.1 (G), R54.1, TP18.1, U2.26 (PB15)
key_col6: Q7.1 (G), R56.1, TP19.1, U2.27 (PA8)
key_fn0: R8.1, SW3.2, U2.36 (SWCLK/PA14)
key_fn1: R9.1, SW4.2, U2.32 (SWDIO/PA13)
key_fn3: R40.1, SW6.2, U2.1 (PC13/TAMPER-RTC)
key_row0: PT1.2 (C), PT2.2 (C), PT3.2 (C), PT4.2 (C), PT5.2 (C), PT6.2 (C), PT7.2 (C), R16.2, TP7.1, U2.14 (ADC5/PA5)
key_row1: PT8.2 (C), PT9.2 (C), PT10.2 (C), PT11.2 (C), PT12.2 (C), PT13.2 (C), PT14.2 (C), R17.2, TP8.1, U2.13 (ADC4/PA4)
key_row2: PT15.2 (C), PT16.2 (C), PT17.2 (C), PT18.2 (C), PT19.2 (C), PT20.2 (C), PT21.2 (C), R18.2, TP9.1, U2.12 (ADC3/PA3)
key_row3: PT22.2 (C), PT23.2 (C), PT24.2 (C), PT25.2 (C), PT26.2 (C), PT27.2 (C), PT28.2 (C), R19.2, TP10.1, U2.11 (ADC2/PA2)
key_row4: PT29.2 (C), PT30.2 (C), PT31.2 (C), PT32.2 (C), PT33.2 (C), PT34.2 (C), PT35.2 (C), R20.2, TP11.1, U2.10 (ADC1/PA1)
key_row5: PT36.2 (C), PT37.2 (C), PT38.2 (C), PT39.2 (C), PT40.2 (C), PT41.2 (C), PT42.2 (C), R21.2, TP12.1, U2.9 (WKUP/ADC0/PA0)
led_b: Q10.1 (G), R60.1, U2.40 (PB5)
led_g: Q9.1 (G), R58.1, U2.39 (PB4)
led_r: Q8.1 (G), R43.1, U2.38 (PB3)
usart1_tx: TP2.1, U2.28 (PA9)
usb1-vbus: C13.1, R38.1, R41.2, U2.37 (PA15)
usb1_N: J1.A7 (D-), J1.B7 (D-), U2.30 (USB1_DM/PA11)
usb1_P: J1.A6 (D+), J1.B6 (D+), U2.31 (USB1_DP/PA12)
usb2_N: J2.A7 (D-), J2.B7 (D-), U2.41 (USB2_DM/PB6)
usb2_P: J2.A6 (D+), J2.B6 (D+), U2.42 (USB2_DP/PB7)

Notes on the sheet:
10kR
tim4_ch4
tim1_ch3
tim2_ch2
5.15V 75ohm 20mA 5V 70ohm 20mA
tim2_ch1
tim4_ch3
tim1_ch2
tim3_ch2
tim3_ch1

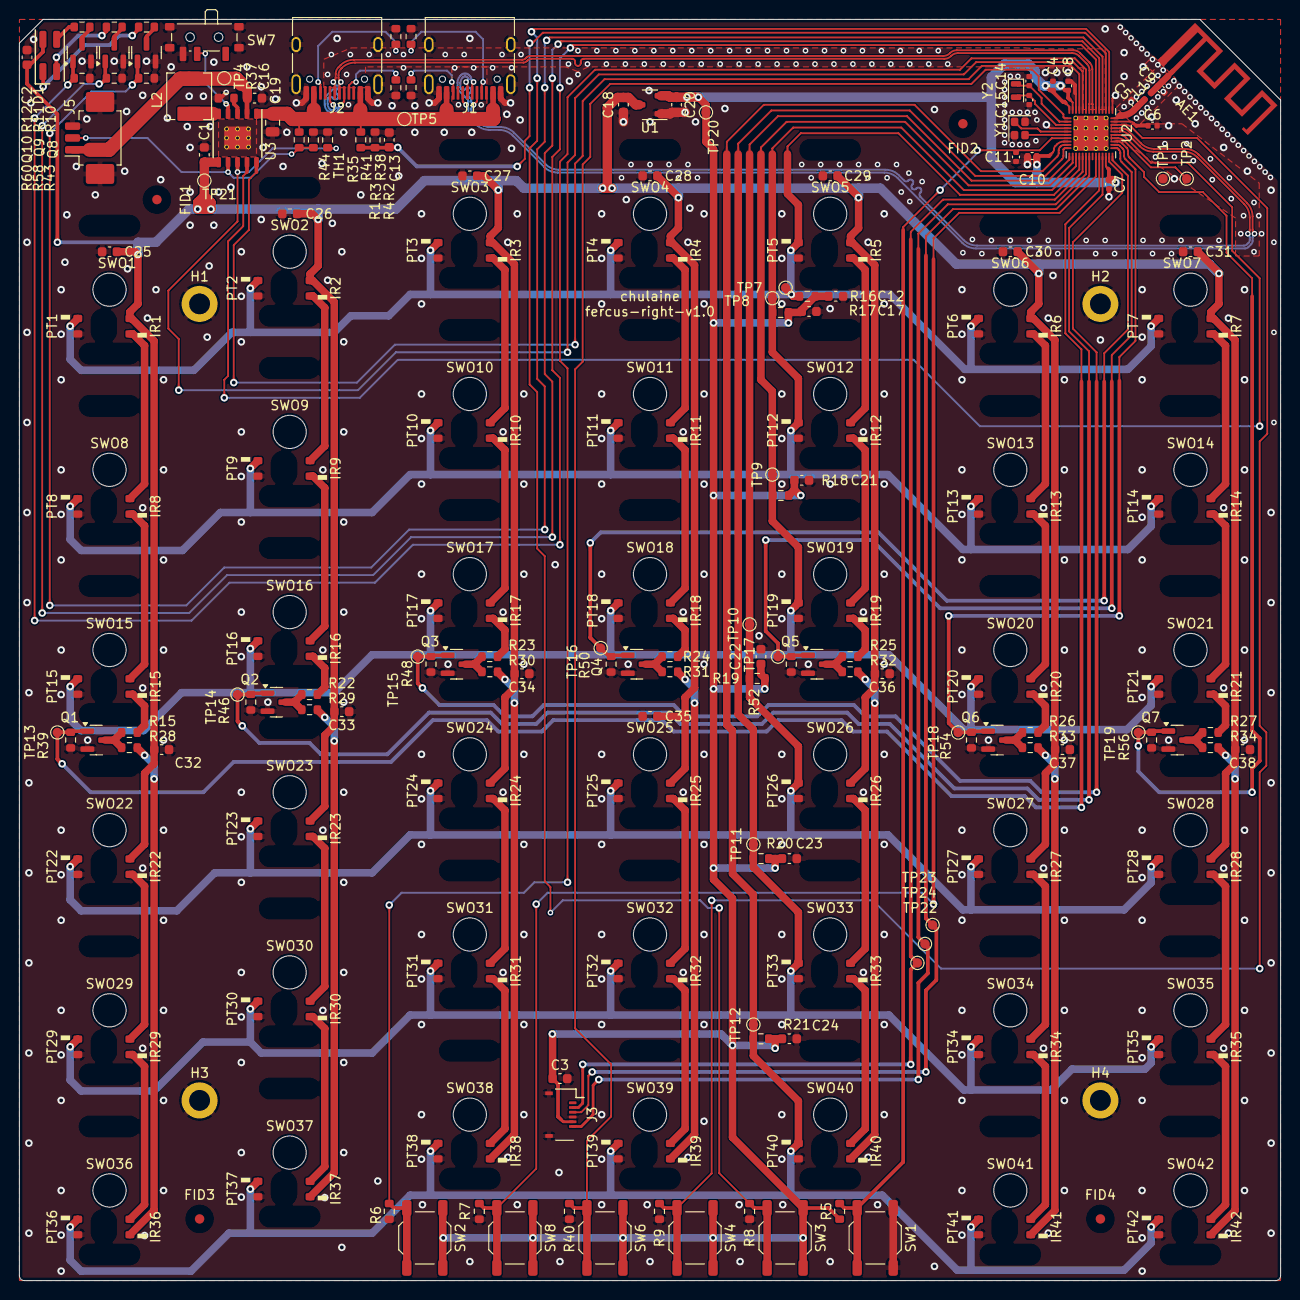
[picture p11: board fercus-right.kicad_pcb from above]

Board: 2 copper layers, 133.0 x 133.0 mm, 273 parts (0 on the bottom side), 109 nets.

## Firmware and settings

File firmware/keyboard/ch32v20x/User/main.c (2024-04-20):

/********************************** (C) COPYRIGHT *******************************
* File Name          : main.c
* Author             : WCH
* Version            : V1.0.0
* Date               : 2021/08/08
* Description        : Main program body.
* Copyright (c) 2021 Nanjing Qinheng Microelectronics Co., Ltd.
* SPDX-License-Identifier: Apache-2.0
*******************************************************************************/ 

/*
 * @Note
 * Composite Keyboard and Mouse Example:
 * This example uses PA4-PA7 and PB12-PB15 to simulate mouse movement and keyboard
 * key pressing respectively, active low. At the same time, it also uses USART2
 * to receive data sent from the host to simulate keyboard key pressing and releasing.
 *
 */

#include "main.h"
#include "config.h"
#include "tmos-connection-mode.h"
#include "tmos-power-manager.h"
//#include "rf_sync.h"
//#include "device_config.h"

/* Global define */
__attribute__((aligned(4))) uint32_t MEM_BUF[BLE_MEMHEAP_SIZE / 4];

#if(defined(BLE_MAC)) && (BLE_MAC == TRUE)
const uint8_t MacAddr[6] = {0x84, 0xC2, 0xE4, 0x03, 0x02, 0x02};
#endif

__attribute__((section(".highcode")))
__attribute__((noinline))
void tmos_Circulation(void)
{
    while(1)
    {
//        rf_sync();
        TMOS_SystemProcess();
    }
}
/* Global Variable */

/*********************************************************************
 * @fn      main
 *
 * @brief   Main program.
 *
 * @return  none
 */
int main(void)
{
    SystemCoreClockUpdate();
    Delay_Init();

    #ifdef DEBUG
        USART_Printf_Init( 115200 );
    #endif
    PRINT("start.%s\n",__TIME__);
//    PRINT("%s\n", VER_LIB);
//    printf( "ChipID:%08x\r\n", DBGMCU_GetCHIPID() );
//    printf("SystemClk:%d\r\n",SystemCoreClock);

//    connection_mode_init(CONN_USB);
//    while (1) {}

    connection_mode = CONN_TMOS_USB;
    connection_mode_init(connection_mode);
    tmos_Circulation();
}

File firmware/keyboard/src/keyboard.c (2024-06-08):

#include "keyboard.h"
#include "HAL.h"
#include "joystick.h"
#include "led.h"
#include "tmos-connection-mode.h"
#include "tmos-power-manager.h"


const uint16_t KB_COL_GPIO_PIN[KB_COL_NUM] = {
        KB_COL_0_GPIO_PIN, KB_COL_1_GPIO_PIN, KB_COL_2_GPIO_PIN,KB_COL_3_GPIO_PIN,
        KB_COL_4_GPIO_PIN, KB_COL_5_GPIO_PIN,KB_COL_6_GPIO_PIN};
GPIO_TypeDef* const KB_COL_GPIO_PORT[KB_COL_NUM] = {
        KB_COL_0_GPIO_PORT, KB_COL_1_GPIO_PORT, KB_COL_2_GPIO_PORT,KB_COL_3_GPIO_PORT,
        KB_COL_4_GPIO_PORT, KB_COL_5_GPIO_PORT, KB_COL_6_GPIO_PORT};

uint8_t kb_col_curr = 0, kb_row_curr = 0;
uint8_t (*kb_layout)[KB_COL_NUM] = kb_lyrs[0];
bool kb_key_state[KB_ROW_NUM][KB_COL_NUM] = {};
uint32_t kb_flag;
uint8_t kb_key_count = 0;

uint32_t kb_ctl = 0;

uint8_t kb_row_read = 0;
static uint16_t kb_adc_value[KB_ADC_SIZE] = {}, kb_adc_buf1[KB_ADC_SIZE] = {};


#if KB_SIDE == KB_SIDE_LEFT
    static uint8_t kb_lyrs[KB_LYR_NUM][KB_ROW_NUM][KB_COL_NUM] = {
        // dovrak debug
//        KEY_OBRACKET_AND_OBRACE, KEY_6_CARET, KEY_7_AMPERSAND, KEY_8_ASTERISK, KEY_9_OPARENTHESIS, KEY_0_CPARENTHESIS, KEY_CBRACKET_AND_CBRACE,
//        KEY_EQUAL_PLUS, KEY_F, KEY_G, KEY_C, KEY_R, KEY_L, KEY_BACKSLASH_VERTICAL_BAR,
//        KEY_TAB, KEY_SINGLE_AND_DOUBLE_QUOTE, KEY_COMMA_AND_LESS, KEY_DOT_GREATER, KEY_P, KEY_Y, KEY_PAGEUP,
//        KEY_ENTER, KEY_A, KEY_O, KEY_E, KEY_U, KEY_I, KEY_PAGEDOWN,
//        KEY_LEFT_SHIFT, KEY_SEMICOLON_COLON, KEY_Q, KEY_J, KEY_K, KEY_X, KEY_END,
//        KEY_EQUAL_PLUS, KEY_F, KEY_G, KEY_C, KEY_R, KEY_L, KEY_BACKSLASH_VERTICAL_BAR,

        // dovrak
        KEY_ESCAPE, KEY_F1, KEY_F2, KEY_F3, KEY_F4, KEY_F5, KEY_DELETE,
        KEY_GRAVE_ACCENT_AND_TILDE, KEY_1_EXCLAMATION_MARK, KEY_2_AT, KEY_3_NUMBER_SIGN, KEY_4_DOLLAR, KEY_5_PERCENT, KEY_HOME,
        KEY_TAB, KEY_SINGLE_AND_DOUBLE_QUOTE, KEY_COMMA_AND_LESS, KEY_DOT_GREATER, KEY_P, KEY_Y, KEY_PAGEUP,
        KEY_ENTER, KEY_A, KEY_O, KEY_E, KEY_U, KEY_I, KEY_PAGEDOWN,
        KEY_LEFT_SHIFT, KEY_SEMICOLON_COLON, KEY_Q, KEY_J, KEY_K, KEY_X, KEY_END,
        KEY_UPARROW, KEY_DOWNARROW, KEY_LEFTARROW, KEY_RIGHTARROW, KEY_LEFT_CONTROL, KEY_SPACEBAR, KEY_LEFT_ALT,

        // qwert game, shift instead of alt
        KEY_ESCAPE, KEY_F1, KEY_F2, KEY_F3, KEY_F4, KEY_F5, KEY_DELETE,
        KEY_GRAVE_ACCENT_AND_TILDE, KEY_1_EXCLAMATION_MARK, KEY_2_AT, KEY_3_NUMBER_SIGN, KEY_4_DOLLAR, KEY_5_PERCENT, KEY_HOME,
        KEY_TAB, KEY_Q, KEY_W, KEY_E, KEY_R, KEY_T, KEY_PAGEUP,
        KEY_ENTER, KEY_A, KEY_S, KEY_D, KEY_F, KEY_G, KEY_PAGEDOWN,
        KEY_LEFT_SHIFT, KEY_Z, KEY_X, KEY_C, KEY_V, KEY_B, KEY_END,
        KEY_UPARROW, KEY_DOWNARROW, KEY_LEFTARROW, KEY_RIGHTARROW, KEY_LEFT_CONTROL, KEY_SPACEBAR, KEY_LEFT_SHIFT,

        // qwert
        KEY_ESCAPE, KEY_F1, KEY_F2, KEY_F3, KEY_F4, KEY_F5, KEY_DELETE,
        KEY_GRAVE_ACCENT_AND_TILDE, KEY_1_EXCLAMATION_MARK, KEY_2_AT, KEY_3_NUMBER_SIGN, KEY_4_DOLLAR, KEY_5_PERCENT, KEY_HOME,
        KEY_TAB, KEY_Q, KEY_W, KEY_E, KEY_R, KEY_T, KEY_PAGEUP,
        KEY_ENTER, KEY_A, KEY_S, KEY_D, KEY_F, KEY_G, KEY_PAGEDOWN,
        KEY_LEFT_SHIFT, KEY_Z, KEY_X, KEY_C, KEY_V, KEY_B, KEY_END,
        KEY_UPARROW, KEY_DOWNARROW, KEY_LEFTARROW, KEY_RIGHTARROW, KEY_LEFT_CONTROL, KEY_SPACEBAR, KEY_LEFT_ALT,
    };

    static uint8_t kb_cntlr_lyrs[KB_LYR_NUM][KB_ROW_NUM][KB_COL_NUM] = {
        CNTLR_NONE, CNTLR_NONE, CNTLR_NONE, CNTLR_NONE, CNTLR_NONE, CNTLR_NONE, CNTLR_NONE,
        CNTLR_BACK, CNTLR_LEFT_STICK_BUTTON, CNTLR_LEFT_STICK_LEFT, CNTLR_LEFT_STICK_RIGHT, CNTLR_LEFT_STICK_UP, CNTLR_LEFT_STICK_DOWN, CNTLR_NONE,
        CNTLR_START, CNTLR_RIGHT_STICK_BUTTON, CNTLR_RIGHT_STICK_LEFT, CNTLR_RIGHT_STICK_RIGHT, CNTLR_RIGHT_STICK_UP, CNTLR_RIGHT_STICK_DOWN, CNTLR_NONE,
        CNTLR_RIGHT_BUMPER, CNTLR_RIGHT_TRIGGER, CNTLR_A, CNTLR_B, CNTLR_X, CNTLR_Y, CNTLR_NONE,
        CNTLR_LEFT_BUMPER, CNTLR_LEFT_TRIGGER, CNTLR_DPAD_LEFT, CNTLR_DPAD_RIGHT, CNTLR_DPAD_UP, CNTLR_DPAD_DOWN, CNTLR_NONE,
        CNTLR_NONE, CNTLR_NONE, CNTLR_NONE, CNTLR_NONE, CNTLR_NONE, CNTLR_NONE, CNTLR_NONE,
    };

    static uint8_t mouse_lyrs[KB_LYR_NUM][KB_ROW_NUM][KB_COL_NUM] = {
            CNTLR_BUTTON_1, CNTLR_BUTTON_2, CNTLR_BUTTON_3, CNTLR_BUTTON_4, CNTLR_BUTTON_5, CNTLR_BUTTON_6, CNTLR_BUTTON_7,
            CNTLR_BUTTON_8, CNTLR_BUTTON_9, CNTLR_BUTTON_10, CNTLR_BUTTON_11, CNTLR_BUTTON_12, CNTLR_BUTTON_13, CNTLR_BUTTON_14,
            CNTLR_BUTTON_15, CNTLR_BUTTON_16, 0x10, 0x11, 0x12, 0x13, 0x14,
            0x15, 0x16, 0x17, 0x18, 0x19, 0x1a, 0x1b,
            0x1c, 0x1d, 0x1e, 0x1f, 0x20, 0x21, 0x22,
            0x23, 0x24, 0x25, 0x26, 0x27, 0x28, 0x29,
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

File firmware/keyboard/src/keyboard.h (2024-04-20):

#ifndef __KEYBOARD_H
#define __KEYBOARD_H

#include "debug.h"
#include "usb_type.h"
#include "app.h"
#include "app_km.h"
#include "usbd_composite.h"

#define KB_LYR_NUM 4
#define KB_ROW_NUM 6
#define KB_COL_NUM 7

#define KB_ROW_GPIO_PORT  GPIOA
#define KB_ROW_0_GPIO_PIN GPIO_Pin_5
#define KB_ROW_1_GPIO_PIN GPIO_Pin_4
#define KB_ROW_2_GPIO_PIN GPIO_Pin_3
#define KB_ROW_3_GPIO_PIN GPIO_Pin_2
#define KB_ROW_4_GPIO_PIN GPIO_Pin_1
#define KB_ROW_5_GPIO_PIN GPIO_Pin_0

#define KB_COL_0_GPIO_PIN GPIO_Pin_10
#define KB_COL_0_GPIO_PORT GPIOB
#define KB_COL_1_GPIO_PIN GPIO_Pin_11
#define KB_COL_1_GPIO_PORT GPIOB
#define KB_COL_2_GPIO_PIN GPIO_Pin_12
#define KB_COL_2_GPIO_PORT GPIOB
#define KB_COL_3_GPIO_PIN GPIO_Pin_13
#define KB_COL_3_GPIO_PORT GPIOB
#define KB_COL_4_GPIO_PIN GPIO_Pin_14
#define KB_COL_4_GPIO_PORT GPIOB
#define KB_COL_5_GPIO_PIN GPIO_Pin_15
#define KB_COL_5_GPIO_PORT GPIOB
#define KB_COL_6_GPIO_PIN GPIO_Pin_8
#define KB_COL_6_GPIO_PORT GPIOA

#define KB_FN_0_GPIO_PIN GPIO_Pin_14
#define KB_FN_0_GPIO_PORT GPIOA
#define KB_FN_1_GPIO_PIN GPIO_Pin_13
#define KB_FN_1_GPIO_PORT GPIOA
#define KB_FN_3_GPIO_PIN GPIO_Pin_13
#define KB_FN_3_GPIO_PORT GPIOC
#define KB_FN_2_GPIO_PIN GPIO_Pin_2
#define KB_FN_2_GPIO_PORT GPIOB
#define KB_FN_NUM 3

#define KB_FN_RELESE 0
#define KB_FN_PRESS 1

extern const uint16_t KB_COL_GPIO_PIN[KB_COL_NUM];
extern GPIO_TypeDef* const KB_COL_GPIO_PORT[KB_COL_NUM];

#define KB_SIDE_LEFT 0
#define KB_SIDE_RIGHT 1
#define KB_SIDE KB_SIDE_LEFT
//#define KB_SIDE KB_SIDE_RIGHT

//#define KB_REPEAT_NONE
//#define KB_MODE_ADC
#define KB_REPEAT_SLOW_DELAY 2000
#define KB_REPEAT_SLOW_RATE 30

//#define BIT(x)                       0x01U<<(x)

//#define KB_CTL_KEYBOARD BIT(1)
//#define KB_CTL_MOUSE BIT(2)
//#define KB_CTL_CNTLR BIT(3)
//#define KB_CTL_ADC BIT(4)

//#define KB_CTL_REPEAT BIT(8)
//#define KB_CTL_REPEAT_SLOW BIT(9)

//#define KB_CTL_LED BIT(1)
#define KB_CTL_USBD          BIT(2)
#define KB_CTL_HOST          BIT(3)
//#define KB_CTL_USART BIT(4)
//#define KB_CTL_USBFS_D          BIT(20)
//#define KB_CTL_USBFS_H          BIT(21)

#define KB_RELESE ((bool)0)
#define KB_PRESS ((bool)1)

enum kb_fn_flag {
    kb_fn_none = (uint8_t)0,
    kb_fn_lyr,
    kb_fn_ctl,
    kb_fn_led,
    kb_fn_uart,
    kb_fn_ms,
    kb_fn_usb,
};

#define KB_FLAG_REPEAT BIT(1)
#define KB_FLAG_COUNT BIT(2)
#define KB_FLAG_FN BIT(3)
//#define KB_FLAG_REPEAT_SLOW BIT(2)
//#define KB_FLAG_DEBUG BIT(2)

void kb_row_gpio_init();
void kb_row_gpio_adc_init();
void kb_adc_dma_init();
void kb_col_gpio_init();
void kb_fn_gpio_init();
void kb_fn_exti_init();
void kb_fn_exti_event_init();

void keyboard_layer_select(uint8_t lyr);
void keyboard_usb_send();
void keyboard_fn_handler();
void kb_digtal_analog_select();
void kb_enable_usbd();
void keyboard_scan_it();
void keyboard_scan_delay();
void keyboard_fn_scan();
void kb_usbhd_combine();
void keyboard_row_read_adc_diff();
void keyboard_row_read_adc_trigger();
void kb_row_adc_cntlr();

void keyboard_row_read();
void keyboard_row_handler();
void keyboard_trigger_handler();

static uint8_t kb_lyrs[KB_LYR_NUM][KB_ROW_NUM][KB_COL_NUM], kb_cntlr_lyrs[KB_LYR_NUM][KB_ROW_NUM][KB_COL_NUM];

extern uint8_t kb_col_curr, kb_row_curr;
extern uint8_t (*kb_layout)[KB_COL_NUM];
extern bool kb_key_state[KB_ROW_NUM][KB_COL_NUM];
extern uint32_t kb_flag;
extern uint8_t kb_key_count;
extern uint32_t kb_ctl;
static uint8_t kb_repeat, kb_device;
static uint16_t kb_row_adc[KB_ROW_NUM];

#define KB_ADC_SIZE (1)
//#define KB_ADC_LEN (KB_ADC_SIZE * 2)
static uint16_t kb_adc_value[KB_ADC_SIZE];

enum kb_repeat {
    KB_REPEAT_NONE,
    KB_REPEAT_FAST,
    KB_REPEAT_SLOW
};

enum kb_device {
    KB_DEVICE_KEYBORAD,
    KB_DEVICE_MOUSE,
    KB_DEVICE_CNTLR,
    KB_DEVICE_COMPOSITE,
    KB_DEVICE_VENDOR,
    KB_DEVICE_KEYBOARD_ADC_DIFF,
    KB_DEVICE_KEYBOARD_ADC_TRIGGER,
    KB_DEVICE_CNTLR_ADC,
};

enum kb_ctl_option {
    KB_CTL_LYR_0 = (uint8_t)0x80,
    KB_CTL_LYR_1,
    KB_CTL_LYR_2,
    KB_CTL_LYR_3,
    KB_CTL_KB_OFF = (uint8_t)0xc0,
    KB_CTL_KB_ON,
    KB_CTL_REPEAT_OFF = 0xe0,
    KB_CTL_REPEAT_ON,
    KB_CTL_ADC_OFF = 0x10,
    KB_CTL_ADC_ON = 0x11,
    KB_CTL_USBD_ON,
    KB_CTL_USBD_OFF,
    KB_CTL_SYSCLK
};
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

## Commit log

2024-04-20 init
    hw: add
    fw: add
    doc: add
    [fercus-dongle.kicad_pcb, fercus-dongle.kicad_sch, fercus-left.kicad_pcb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]
2024-06-08 merge
    fw:
    - fix usb product string, vid
    - add rf_phy_hop
    - add RF_BondingErase()
    - change default layout key fn to pause
    - fix power manager poweroff when usb disconnect
    - add usb compatibility interface
    hw:
    - change eta9084 iset resistor footprint to 0402
    - change fpc connector part
    - fix ir resistor value
    - change pcb thinkness to 1.6mm
    - fix footprint of pt and ir
    - fix rf ant trace
    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
    [fercus-dongle.kicad_pcb, fercus-dongle.kicad_sch, fercus-left.kicad_pcb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]
2024-09-21 merge
    - fix sch
    - fix plate
    - rename to fercus-dongle-usb-a
    doc:
    - add assembly
    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
    [fercus-dongle.kicad_pcb, fercus-dongle.kicad_sch, fercus-left.kicad_pcb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]
2025-12-21 hw: add footprint library
